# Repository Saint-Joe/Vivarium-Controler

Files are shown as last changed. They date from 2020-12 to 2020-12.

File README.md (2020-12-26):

# Vivarium Controller
Use common inexpensive open-source hardware and software to control and the environment in a Vivarium, Terrarium, or Palladium.
* esp8266 and for sensors and controllers
* MQTT messaging protocol for communication
* RaspberryPi running Home Assistant w/ MQTT Broker and Node-Red for automation
* Adafruit IO for anywhere access to environment data

## Goals:
1. Simple solution for monitoring temperature and humidity in a Vivarium, Terrarium, or Palladium
1. Use automation to control (Home Assistant, Adafruit IO, etc)
	1. Lights
	1. Misting system
	1. Fans
  
## Completed:
### Sensor Pack
* Create a Sensor Pack for monitoring temperature and humidity 
	* Publish MQTT Broker, monitor MQTT and enable 4 pins on the esp board 
	* Use MQTT to control 4 pins
	* basic logic to discard one bad reading from the HTU21D sensor
#### Sensor Pack Hardware & Supplies
* [NodeMcu Mini D1](https://www.amazon.com/gp/product/B081PX9YFV/)
* [HTU21D Temperature Humidity Sensor Breakout Module](https://www.amazon.com/dp/B07VRNW2X6/)
* [30 awg Silicone Electrical Wire](https://www.amazon.com/gp/product/B07G7R9BVJ/)
* [Braided Sleeving](https://www.amazon.com/gp/product/B071JH14WZ/)
* [LulzBot PolyLite PLA](https://www.amazon.com/gp/product/B01IAVQI2E/) for the cases

## Wish List/ToDo:
### Misting Controller
* Build a esp8266/relay to control main power for misting pump
* Use [Solenoid valves](https://www.mistking.com/Solenoid-Valve-NC.html) to control which habitat is misted
* Error checking to limit over misting
* Modify "Sensor Pack" to monitor reservoir float valve
* limit "on" time (x sec in y hours), this will prevent bad data from drowning the habitat
  
### Light Controller
* Build esp8266/relay to control 24v T5 LED light strips
	* [24v T5 LED light strips](https://www.amazon.com/gp/product/B088CZNWHQ)
	* [LED Driver 200 Watts 24V](https://www.amazon.com/gp/product/B07MZV7148)
	* [Relay](https://www.amazon.com/dp/B01HCFJC0Y/)

### Habitat Display
* Use esp8266 and oled to display habitat data as is streams through the MQTT broker

### Web Server
Create a simple web interface for the Sensor Pack that would alow you to make changes to the sensors; these changes would be saved to the eeprom and loaded on reboot
* Change WiFi SSID and Secret 
* Change MQTT Server, user, or password
* Change the Sensor Pack's device ID
* Modify the Temperature and Humidity offset values

### Fan Pack
Use an esp8266 and a 5v fan to control humidity in the habitat
* 3d printed fan holder that will sit in one of my 60mm vents
* Logic to monitor humitity and enable fan to maintain desired humitity levels
	* will need to work with the mising controler
* Maybe a [pwm](https://github.com/faeibson/ESPPWMFanControl) fan? 
	* requires a 12v power supply; but that could be regulated to control the 3.3v controler

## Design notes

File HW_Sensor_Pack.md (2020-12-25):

# Vivarium Controller HW Build

## Prerequisites 

* MQTT Broker, local or public internet. MQTT is a lightweight messaging protocol that facilitates data transfer or commands to and from IoT devices.
  * Consider running Home Assistant w/ Mosquitto broker 
* Files from https://github.com/Saint-Joe/Vivarium-Controller
  * 3d Printer to print cases
  * Sensor Pack software 
* Basic understanding of electronics and open source software (aka patience)
* Soldering Iron, 3D Printer, etc..
* Watch The Hook Up's [Home Assistant Beginners Guide video](https://youtu.be/sVqyDtEjudk)

## Hardware Assembly
1. Gather the parts and supplies 
	1. 3d printed cases
	1. Circuit boards
	1. Wire and braided sleeve
	1. Soldering Iron and Solder
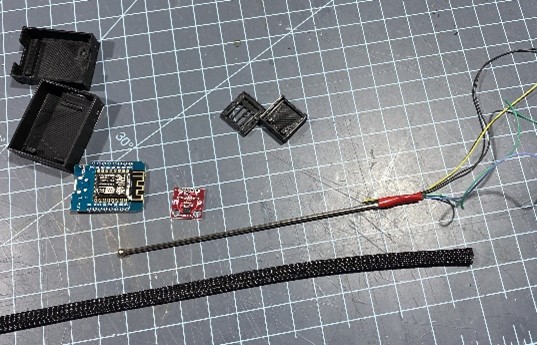
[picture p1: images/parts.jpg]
	* 
1. Cut 14” of the Braided Sleeving or length as you desire
	1. Heat ends to prevent unraveling
	1. Thread 4 wires through sleeving, leave on the spool for now.
1. Put wire and sleeving through the hole on the HTU21D case
1. Strip 1/8 (3mm) from the end of the wire not attached to the spool
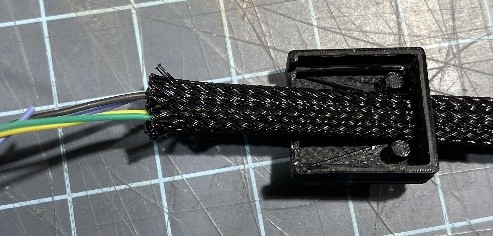
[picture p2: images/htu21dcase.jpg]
	* 
1. Solder the wires to the HTU21D. Wires should run out the back; this will prevent them from covering the sensor. Document the wire colors once this is done.
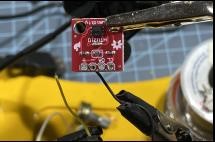
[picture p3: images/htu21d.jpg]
	* 
1. From the wire spool, pull your wires back through the sleeving, make sure your sleeving stays in the case
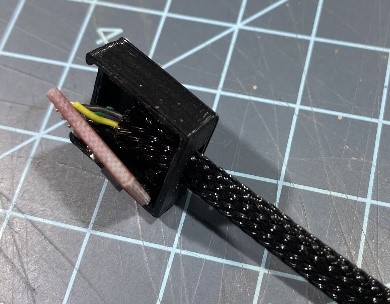
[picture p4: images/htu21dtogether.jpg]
	* 
1. Use hot-glue to secure the HTU21D in the case; gluing the sleeving down to reduce strain on the wires. 
1. Use plastic cement to attach the HTU21D case lid.
1. With no tension on the wires in the braided sleeve, cut the wires just under 1 inch(20mm) from the end of the sleeve(we can pull the sleeve back to solder.
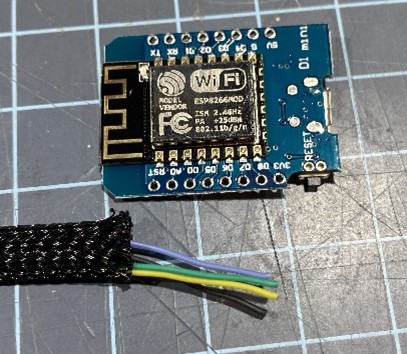
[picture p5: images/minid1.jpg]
	* 
1. Run wires and sleeve into the Mini D1 case. The vents on the HTU21D case should be up once this step is complete. 
	* get started
1. Solder the wires on to the Mini D1 (D1 is Clock and D2 is Data).
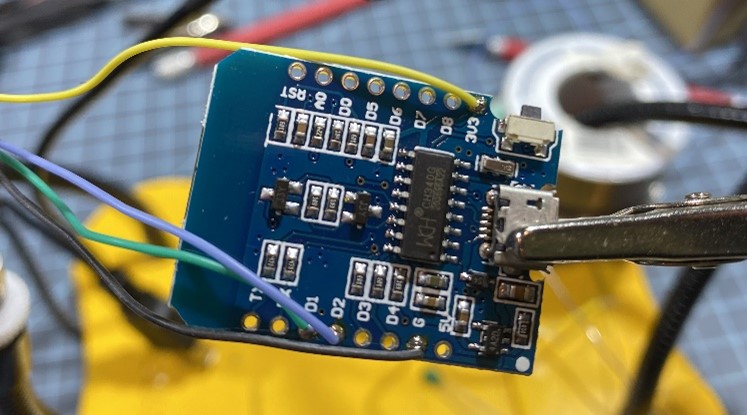
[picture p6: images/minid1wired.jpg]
	* 
1. Install and test software. I use MQTT Explorer to see data; we are looking for the 5 pins and the temperature and humidity data
	1. You will need to update the WiFi and MQTT server settings
	1. Each Sensor Pack should have a unique ID
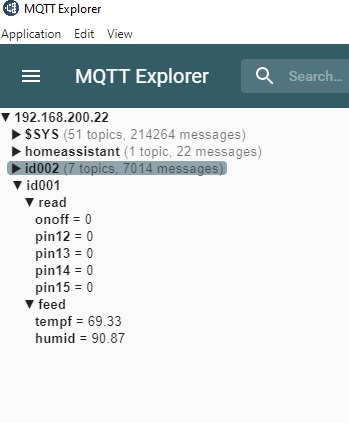
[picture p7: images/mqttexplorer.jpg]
	* 
1. Hot-glue the Mini D1 into its case and then put the top on.
	1. Make sure that the sleeve is oriented so that the two cases will align back to back.
	1. Add some hot-glue for strain relief
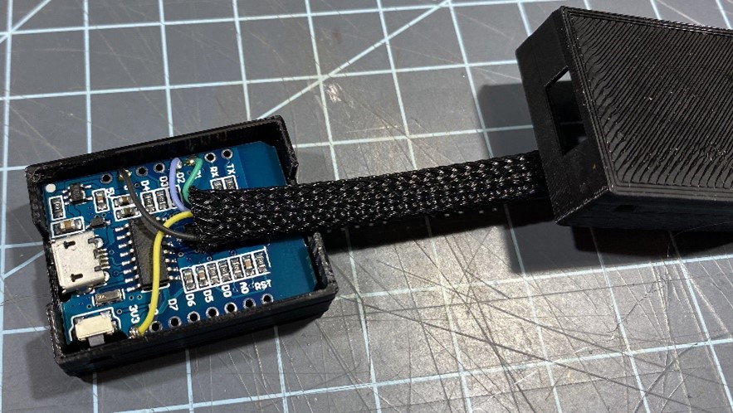
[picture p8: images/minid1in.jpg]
	* 
1. Use some VHB tape to attach the sensor in your habitat and the controller to the back or side. 
1. Use a usb charger or usb battery pack to power your device.

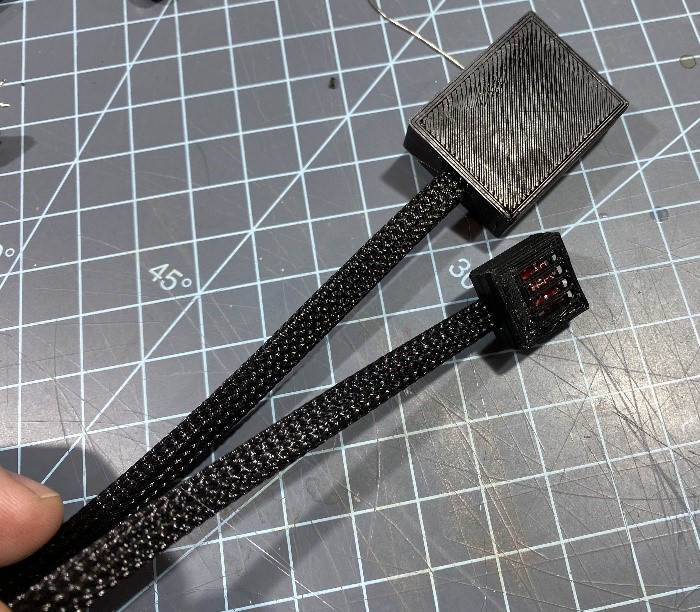
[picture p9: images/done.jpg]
done


## Addtional Testing

Using a the software MQTT Explorer, you can send a message to topic ...unitID../read/onoff with a data packet of 1 to enable the builtin LED or 0 to turn the LED off. This could be usefull if you have 10+ and you need to find

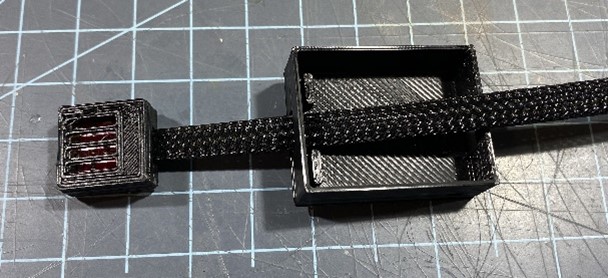
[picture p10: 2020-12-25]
images/minid1case.jpg

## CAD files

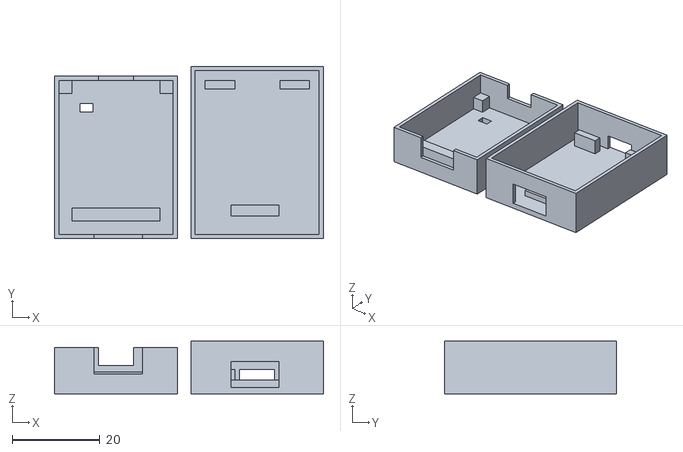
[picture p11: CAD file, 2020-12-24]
3dPrints/D1Mini_Case_V01.stl
61.2 x 39.2 x 12.0

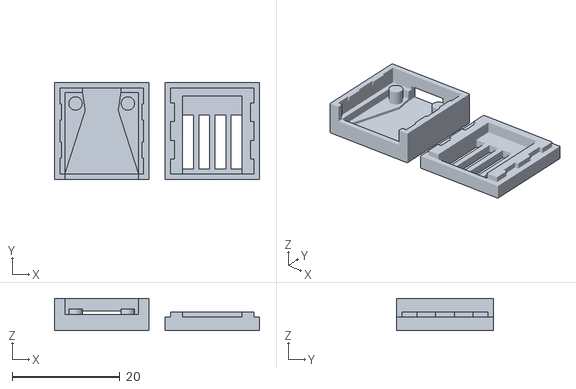
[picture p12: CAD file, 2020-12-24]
3dPrints/HTU_case_V01.stl
38.0 x 18.0 x 6.00

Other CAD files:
3dPrints/D1Mini_Case_V01.skp
3dPrints/HTU_case_V01.skp

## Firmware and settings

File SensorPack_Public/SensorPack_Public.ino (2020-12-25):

/***************************************************
  MIT license
  Permission is hereby granted, free of charge, to any person obtaining a copy of this 
  software and associated documentation files (the "Software"), to deal in the Software 
  without restriction, including without limitation the rights to use, copy, modify, merge,
  publish, distribute, sublicense, and/or sell copies of the Software, and to permit persons
  to whom the Software is furnished to do so, subject to the following conditions:
  - Any use or redistubuted of this software, in whole or in part must retain the MIT License
  - Contributers must be attributed in this header
  - MIT license, all text in this header will be included in any redistribution  
  THE SOFTWARE IS PROVIDED "AS IS", WITHOUT WARRANTY OF ANY KIND, EXPRESS OR IMPLIED, 
  INCLUDING BUT NOT LIMITED TO THE WARRANTIES OF MERCHANTABILITY, FITNESS FOR A PARTICULAR 
  PURPOSE AND NONINFRINGEMENT. IN NO EVENT SHALL THE AUTHORS OR COPYRIGHT HOLDERS BE 
  LIABLE FOR ANY CLAIM, DAMAGES OR OTHER LIABILITY, WHETHER IN AN ACTION OF CONTRACT, TORT
  OR OTHERWISE, ARISING FROM, OUT OF OR IN CONNECTION WITH THE SOFTWARE OR THE USE OR OTHER
  DEALINGS IN THE SOFTWARE.
Contributor:
- SensorPack V01.01: Keith Talbot
- Adafruit MQTT : Tony DiCola for Adafruit Industries.
- Adafruit HTU21D-F : Adafruit Industries
- Paulus Schoutsen (https://www.home-assistant.io/blog/2015/10/11/measure-temperature-with-esp8266-and-report-to-mqtt/)
Version history
- V01.01 First Version
- V01.02 Update get Humidity and Temp with error controls; add var to control if returns Celsius or Fahrenheit
 ****************************************************/
#include <ESP8266WiFi.h>
#include "Adafruit_MQTT.h"
#include "Adafruit_MQTT_Client.h"

/************************* WiFi Access Point *********************************/

#define WLAN_SSID       "...your ssid..."
#define WLAN_PASS       "...secret key..."
#define CODE_VER        "01.02"


/************************* MQTT Setup *********************************/

#define AIO_SERVER      "XXX.XXX.XXX.XXX"       //MQTT Broker host name (mqtt.domain.com) or ip
#define AIO_SERVERPORT  1883                   // use 8883 for SSL
#define AIO_USERNAME    "...mqttuser..."
#define AIO_KEY         "...mqttpass..."
#define AIO_SENSOR      "...my.ID..."          //user defined id, useful if you have many sensor packs

//*This has beeen modified to work with a local MQTT server, AIO_SENSOR is not needed for Adafruit IO


/************************* i2c Setup *********************************/
#include <Wire.h>
#include "Adafruit_HTU21DF.h" // **for IO and temp/humid
float f_tempf = 0.0;
float f_temp = 0.0;
float old_temp = 0.0;
float f_hum = 0.0;
float old_hum = 0.0;
float temp_adjust = 0.0;                  // celsius  e.g -2 or 2
float hum_adjust = 0.0;                   // e.g. +20, -20
float sensor_diff = 1.0;                  // if sensor change more than this; they will not err and wait for next pass(max 5)
int TempFahrenheit = 1;                   // 1 = report in fahrenheit

Adafruit_HTU21DF htu = Adafruit_HTU21DF(); // **for IO and temp/humid


/************ Global State (you don't need to change this!) ******************/

// Create an ESP8266 WiFiClient class to connect to the MQTT server.
WiFiClient client;
// or... use WiFiClientSecure for SSL
//WiFiClientSecure client;

// Setup the MQTT client class by passing in the WiFi client and MQTT server and login details.
Adafruit_MQTT_Client mqtt(&client, AIO_SERVER, AIO_SERVERPORT, AIO_USERNAME, AIO_KEY);

/****************************** Feeds ***************************************/

// Setup a feeds for publishing to changes.
Adafruit_MQTT_Publish tempf = Adafruit_MQTT_Publish(&mqtt, AIO_SENSOR "/feed/tempf");
Adafruit_MQTT_Publish humid = Adafruit_MQTT_Publish(&mqtt, AIO_SENSOR "/feed/humid");
Adafruit_MQTT_Publish pubonoffled = Adafruit_MQTT_Publish(&mqtt, AIO_SENSOR "/read/onoff");
Adafruit_MQTT_Publish pubpin12 = Adafruit_MQTT_Publish(&mqtt, AIO_SENSOR "/read/pin12");
Adafruit_MQTT_Publish pubpin13 = Adafruit_MQTT_Publish(&mqtt, AIO_SENSOR "/read/pin13");
Adafruit_MQTT_Publish pubpin14 = Adafruit_MQTT_Publish(&mqtt, AIO_SENSOR "/read/pin14");
Adafruit_MQTT_Publish pubpin15 = Adafruit_MQTT_Publish(&mqtt, AIO_SENSOR "/read/pin15");

// Setup a feed for subscribing to changes.
Adafruit_MQTT_Subscribe onoffled = Adafruit_MQTT_Subscribe(&mqtt, AIO_SENSOR "/read/onoff");
Adafruit_MQTT_Subscribe pin12 = Adafruit_MQTT_Subscribe(&mqtt, AIO_SENSOR "/read/pin12");
Adafruit_MQTT_Subscribe pin13 = Adafruit_MQTT_Subscribe(&mqtt, AIO_SENSOR "/read/pin13");
Adafruit_MQTT_Subscribe pin14 = Adafruit_MQTT_Subscribe(&mqtt, AIO_SENSOR "/read/pin14");
Adafruit_MQTT_Subscribe pin15 = Adafruit_MQTT_Subscribe(&mqtt, AIO_SENSOR "/read/pin15");

//*This has beeen modified to work with a local MQTT server, feed strings would need to be adjusted to work with AIO


/*****************************************************************************/
/********************************* Setup *************************************/
/*****************************************************************************/

void setup() {
  pinMode(BUILTIN_LED, OUTPUT);  //enable ESP8266 built in led
  pinMode(12, OUTPUT);
  pinMode(13, OUTPUT);  
  pinMode(14, OUTPUT);  
  pinMode(15, OUTPUT);  
  
  digitalWrite(BUILTIN_LED, HIGH);  // Turn the LED off by making the voltage HIGH 
  digitalWrite(12, LOW);
  digitalWrite(13, LOW);
  digitalWrite(14, LOW);
  digitalWrite(15, LOW);
  
  Serial.begin(115200);
  delay(10000);

  Serial.println("\n\n***********************Starting***********************");
  Serial.println("\n\tSensor Pack");
  Serial.print("\tCode Version: \t\t");
  Serial.println(CODE_VER);
  Serial.print("\tDevice ID: \t\t");
  Serial.println(AIO_SENSOR);
  Serial.println("\n******************************************************");

  // Connect to WiFi access point.
  Serial.println(); Serial.println();
  Serial.print("Connecting to ");
  Serial.println(WLAN_SSID);
  WiFi.begin(WLAN_SSID, WLAN_PASS);
  while (WiFi.status() != WL_CONNECTED) {
    delay(500);
    Serial.print(".");
  }
  Serial.println();
  Serial.println("WiFi connected");
  Serial.println("IP address: "); Serial.println(WiFi.localIP());
  delay(1500);

  // Setup callbacks
  onoffled.setCallback(onoffcallback);
  pin12.setCallback(pin12callback);
  pin13.setCallback(pin13callback);
  pin14.setCallback(pin14callback);
  pin15.setCallback(pin15callback);

  // Setup MQTT subscription
  mqtt.subscribe(&onoffled);
  mqtt.subscribe(&pin12);
  mqtt.subscribe(&pin13);
  mqtt.subscribe(&pin14);
  mqtt.subscribe(&pin15);

  // Setup temperature and humidity sensor
  if (!htu.begin()) {   // **for IO and temp/humid
    Serial.println("Couldn't find sensor!");
    while (1);
  }
  delay(1500);
  old_temp = htu.readTemperature();
  delay(1500);

  //old_hum = htu.readHumidity();
  old_hum = constrain(htu.readHumidity(), 0.0, 99.99);  

  MQTT_connect();  // Connect to the MQTT Broker

  // Publish pin states
  pubonoffled.publish(0);
  pubpin12.publish(0);
  pubpin13.publish(0);
  pubpin14.publish(0);
  pubpin15.publish(0);
  
}

/*****************************************************************************/
/******************************* void loop ***********************************/
/*****************************************************************************/

void loop() {

  MQTT_connect();                               //Make sure we are connected 
  mqttPublish();                                //Post sensor data to the MQTT Broker 
  mqtt.processPackets(10000);                   //Listen for MQTT Subscriptions(time)
  if(! mqtt.ping()) {mqtt.disconnect();}        // ping MQTT Broker to keep alive

}


/*****************************************************************************/
/***************************** MQTT Broker ***********************************/
/*****************************************************************************/

// Function to connect and reconnect as necessary to the MQTT server.
// Should be called in the loop function and it will take care if connecting.
void MQTT_connect() {
  int8_t ret;

  // Stop if already connected.
  if (mqtt.connected()) {
    return;
  }

  Serial.print("Connecting to MQTT... ");

  uint8_t retries = 3;
  while ((ret = mqtt.connect()) != 0) { // connect will return 0 for connected
       Serial.println(mqtt.connectErrorString(ret));
       Serial.println("Retrying MQTT connection in 5 seconds...");
       mqtt.disconnect();
       delay(5000);  // wait 5 seconds
       retries--;
       if (retries == 0) {
         // basically die and wait for WDT to reset me
         while (1);
       }
  }
  Serial.println("MQTT Connected!");
}

/*****************************************************************************/
/***************************** MQTT Publish **********************************/
/*****************************************************************************/

void mqttPublish() {
  
  float post_temp = gettemp();  
    delay(100);
  float post_hum = gethum();  
 
  Serial.print(F("\nSending Temperature "));
  Serial.print(post_temp);                             //or (newTemp)
  Serial.print("...");
                                                    //Publish temp to MQTT 
  if (! tempf.publish(post_temp)) {                   //or (newTemp)
    Serial.println(F("Failed"));
  } else {
    Serial.println(F("OK!"));
  }

  Serial.print(F("Sending Humidity "));
  Serial.print(post_hum);
  Serial.print("...");

  if (! humid.publish(post_hum)) {                    //Publish humidity to MQTT   
    Serial.println(F("Failed"));
  } else {
    Serial.println(F("OK!"));
  }
  
}


/*****************************************************************************/
/****************************** Call Backs ***********************************/
/*****************************************************************************/

void onoffcallback(char *data, uint16_t len) {
  Serial.print("Hey we're in a onoff callback, the value is: ");
  Serial.println(data);
String str_data = data;
      if (str_data  == "1"){
        digitalWrite(BUILTIN_LED, LOW);   // Turn the LED on (Note that LOW is the voltage level
        }
      if (str_data  == "0"){
        digitalWrite(BUILTIN_LED, HIGH);   // Turn LED off 
        }
}


void pin12callback(char *data, uint16_t len) {
  Serial.print("PIN12 callback, the value is: ");
  Serial.println(data);
String str_data = data;
      if (str_data  == "1"){
        digitalWrite(12, HIGH);
        }
      if (str_data  == "0"){
        digitalWrite(12, LOW);
        }
}


void pin13callback(char *data, uint16_t len) {
  Serial.print("PIN13 callback, the value is: ");
  Serial.println(data);
String str_data = data;
      if (str_data  == "1"){
        digitalWrite(13, HIGH);
        }
      if (str_data  == "0"){
        digitalWrite(13, LOW);
        }
}


void pin14callback(char *data, uint16_t len) {
  Serial.print("PIN14 callback, the value is: ");
  Serial.println(data);
String str_data = data;
      if (str_data  == "1"){
        digitalWrite(14, HIGH);
        }
      if (str_data  == "0"){
        digitalWrite(14, LOW);
        }
}


void pin15callback(char *data, uint16_t len) {
  Serial.print("PIN15 callback, the value is: ");
  Serial.println(data);
String str_data = data;
      if (str_data  == "1"){
        digitalWrite(15, HIGH);
        }
      if (str_data  == "0"){
        digitalWrite(15, LOW);
        }
}


/*****************************************************************************/
/*************************** Get Temperature *********************************/
/*****************************************************************************/


int errTempCnt;
float gettemp() {

float newTemp = htu.readTemperature(); 
  newTemp = newTemp + temp_adjust;                       //if needed we can adjust the temp(calabrate)

Serial.print("\nTemperature(New/Old):\t");
Serial.print(newTemp); Serial.print("c \t\t");
Serial.print(old_temp);Serial.println("c");
Serial.print("Temperature error count:\t");   Serial.println(errTempCnt);  

    if (checkBound(newTemp, old_temp, sensor_diff)) {
      //change is greater than sensor diff
      errTempCnt++;
      if (errTempCnt > 5){                              //if we get 5 errors with out an update,
        old_temp = newTemp;                             //assume current data is bad and update 
        errTempCnt = 0;
        Serial.println("Temperature updated by error count");  
      }
    } else {
      //Change is with in the sensor diff range
      old_temp = newTemp;
      errTempCnt = 0;                                   //we have a good temp change; reset errTempCnt
      Serial.println("Temperature updated");  
    }

  if (TempFahrenheit == 1){
    float old_temp_f = ((old_temp * 1.8) + 32);
    return old_temp_f;  
  } else {
    return old_temp;
  }
}


/*****************************************************************************/
/***************************** Get Humidity **********************************/
/*****************************************************************************/


/* constrain(x, a, b)
x: if x is between a and b.
a: if x is less than a.
b: if x is greater than b.
sensVal = constrain(sensVal, 10, 150);  // limits range of sensor values to between 10 and 150
*/

int errHumCnt;
float gethum() {

  float newHum = htu.readHumidity();                 //get humidity
    newHum = constrain(newHum, 0.0, 99.99);
    newHum = newHum + hum_adjust;                    //if needed we can adjust the temp(calabrate)

Serial.print("\nHumidity(New/Old):\t");
Serial.print(newHum ); Serial.print("c \t\t");
Serial.print(old_hum);Serial.println("c");
Serial.print("Humidity error count:\t");   Serial.println(errHumCnt);  

    if (checkBound(newHum, old_hum, sensor_diff)) {
      //change is greater than sensor diff
      errHumCnt++;
      if (errHumCnt > 5){                              //if we get 5 errors with out an update,
        old_hum = newHum;                             //assume current data is bad and update 
        errHumCnt = 0;
        Serial.println("Humidity updated by error count");  
      }
    } else {
      //Change is with in the sensor diff range
      old_hum = newHum;
      errHumCnt = 0;                                   //we have a good temp change; reset errTempCnt
      Serial.println("Humidity updated");  
    }
  return old_hum;                                     //retutn old_hum record there was an error or it was already updated from newHum
}


/*****************************************************************************/
/****************************** Check Bound **********************************/
/*****************************************************************************/

bool checkBound(float newValue, float prevValue, float maxDiff) {
  return !isnan(newValue) &&
         (newValue < prevValue - maxDiff || newValue > prevValue + maxDiff);
}

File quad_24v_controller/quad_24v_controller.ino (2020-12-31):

/*
 * Hardware
 *  esp8266 board
 *  2n2222 transitor 
 *  12v 4 wire fan
 *  12v power supply
 *  
 * Setup 
 *  Fan positive and ground connected to 12v power supply
 *  Ground from power supply conneted to esp ground
 *  Pin D8 (GPIO15) connected to the fans PWM
 * 
 * Adjust fanSpead between 1 and 100
 * 
 */
#include <ESP8266WiFi.h>
#include "Adafruit_MQTT.h"
#include "Adafruit_MQTT_Client.h"
#include "CONFIG.h"

WiFiClient client;


/*****************************MQTT  Feeds ************************************/

Adafruit_MQTT_Client mqtt(&client,MQTT_SERVER, MQTT_SERVERPORT, MQTT_USERNAME, MQTT_PASSWORD);

// Setup a feeds for publishing to the MQTT Server
Adafruit_MQTT_Publish statusmessage = Adafruit_MQTT_Publish(&mqtt, UNIQUE_ID "/feed/ello");

// Setup subscriptions to pull from the MQTT Server
Adafruit_MQTT_Subscribe QuadLevelOne = Adafruit_MQTT_Subscribe(&mqtt, UNIQUE_ID "/feed/levelone");
Adafruit_MQTT_Subscribe QuadLevelTwo = Adafruit_MQTT_Subscribe(&mqtt, UNIQUE_ID "/feed/leveltwo");
Adafruit_MQTT_Subscribe QuadLevelThree = Adafruit_MQTT_Subscribe(&mqtt, UNIQUE_ID "/feed/levelthree");
Adafruit_MQTT_Subscribe QuadLevelFour = Adafruit_MQTT_Subscribe(&mqtt, UNIQUE_ID "/feed/levelfour");
Adafruit_MQTT_Subscribe onoffled = Adafruit_MQTT_Subscribe(&mqtt, UNIQUE_ID "/read/onoff");


#define BASEone 0                                       //PWM
#define BASEtwo 3
#define BASEthree 13
#define BASEfour 16

int i;                                               // Counter


void setup() {
  delay(2000);
  Serial.begin(115200);
  delay(2000);
    Serial.println("Hello World!");  

  connectWifi();                                       

  pinMode(BASEone, OUTPUT);
  pinMode(BASEtwo, OUTPUT);
  pinMode(BASEthree, OUTPUT);
  pinMode(BASEfour, OUTPUT);
  analogWriteRange(100);                               // range 1 - 100 for the fan
  analogWriteFreq(500); 

  //setup mqtt callbacks
  QuadLevelOne.setCallback(oneCallback);
  QuadLevelTwo.setCallback(twoCallback);
  QuadLevelThree.setCallback(threeCallback);
  QuadLevelFour.setCallback(fourCallback);
  onoffled.setCallback(onoffcallback);
  // Setup MQTT subscription
  mqtt.subscribe(&QuadLevelOne);
  mqtt.subscribe(&QuadLevelTwo);
  mqtt.subscribe(&QuadLevelThree);
  mqtt.subscribe(&QuadLevelFour);
  mqtt.subscribe(&onoffled);


  MQTT_connect();  // Connect to the MQTT Broker

  statusmessage.publish("Alive!");

  
}

void loop() {
  
  MQTT_connect();                               //Make sure we are connected 
  mqtt.processPackets(10000);                   //Listen for MQTT Subscriptions(time)
  if(! mqtt.ping()) {mqtt.disconnect();}        // ping MQTT Broker to keep alive

}



/*****************************************************************************/
/****************************** Call Backs ***********************************/
/*****************************************************************************/



void onoffcallback(char *data, uint16_t len) {
  Serial.print("Hey we're in a onoff callback, the value is: ");
  Serial.println(data);
}

void oneCallback(char *data, uint16_t len) {
  Serial.print("oneCallback, the value is: ");
  Serial.println(data);
  int onePWMrate = atoi(data);
  analogWrite(BASEone, onePWMrate);
}

void twoCallback(char *data, uint16_t len) {
  Serial.print("twoCallback, the value is: ");
  Serial.println(data);
    int twoPWMrate = atoi(data);
    analogWrite(BASEtwo, twoPWMrate);
}

void threeCallback(char *data, uint16_t len) {
  Serial.print("threeCallback, the value is: ");
  Serial.println(data);
    int threePWMrate = atoi(data);
    analogWrite(BASEthree, threePWMrate);
}

void fourCallback(char *data, uint16_t len) {
  Serial.print("fourCallback, the value is: ");
  Serial.println(data);
    int fourPWMrate = atoi(data);
    analogWrite(BASEfour, fourPWMrate);
}

/*****************************************************************************/
/**************************** WiFi Service ***********************************/
/*****************************************************************************/


void connectWifi(){

// Connect to WiFi access point.
  Serial.println(); Serial.println();
  Serial.print("Connecting to ");
  Serial.println(WLAN_SSID);
  WiFi.begin(WLAN_SSID, WLAN_PASS);
  while (WiFi.status() != WL_CONNECTED) {
    delay(500);
    Serial.print(".");
  }
  Serial.println();
  Serial.println("WiFi connected");
  Serial.println("IP address: "); Serial.println(WiFi.localIP());
  delay(1500);
  
  
}


/*****************************************************************************/
/***************************** MQTT Broker ***********************************/
/*****************************************************************************/

// Function to connect and reconnect as necessary to the MQTT server.
// Should be called in the loop function and it will take care if connecting.
void MQTT_connect() {
  int8_t ret;

  // Stop if already connected.
  if (mqtt.connected()) {
    return;
  }

  Serial.print("Connecting to MQTT... ");

  uint8_t retries = 3;
  while ((ret = mqtt.connect()) != 0) { // connect will return 0 for connected
       Serial.println(mqtt.connectErrorString(ret));
       Serial.println("Retrying MQTT connection in 5 seconds...");
       mqtt.disconnect();
       delay(5000);  // wait 5 seconds
       retries--;
       if (retries == 0) {
         // basically die and wait for WDT to reset me
         while (1);
       }
  }
  Serial.println("MQTT Connected!");
}

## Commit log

2020-12-24 Update SensorPack_V01_01_HTU21DespMQT_public.ino
    added comments
2020-12-24 Update SensorPack_V01_01_HTU21DespMQT_public.ino
    Update the "get Humidity and Temp" process with error controls;
    Add a variable to control if MQTT returns temp as Celsius or Fahrenheit;
2020-12-24 Update SensorPack_V01_01_HTU21DespMQT_public.ino
    Added a contributor
